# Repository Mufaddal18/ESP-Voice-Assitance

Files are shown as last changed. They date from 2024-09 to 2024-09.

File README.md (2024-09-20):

# ESP-Voice-Assitance

🚀 Excited to share my latest project: a fully integrated PCB for a voice assistant inspired by Avi Patel’s Gemini Voice Assistant!

This innovative design utilizes the Deepgram API for seamless speech-to-text conversion and leverages the Gemini API for intelligent responses, all while harnessing Google Text-to-Speech for natural-sounding replies.

🔑 Key Features:

1. Integrated Components: Powered by the ESP32, featuring a USB to TTL circuit, I2S microphone, and robust amplifier for top-notch performance.

2. Speech-to-Text Conversion: Impressively quick response time with Deepgram API.

3. Smart Audio Switching: Automatically toggles between speaker and earphone output for a personalized listening experience.

4. WAV File Storage: Efficiently processes longer questions by storing them as WAV files on an SD card.

5. Replay Functionality: A dedicated button to replay the last response, enhancing user interaction.

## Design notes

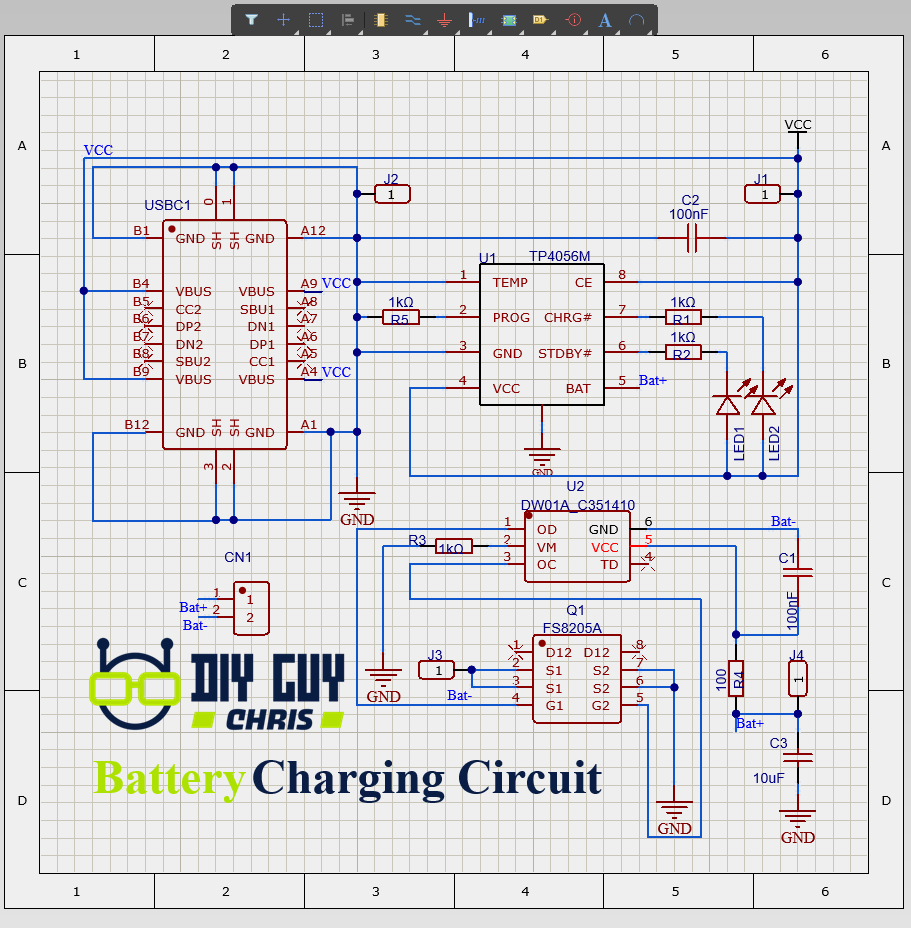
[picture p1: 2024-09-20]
Refrence/FD6H0HMLDD3WI26.webp

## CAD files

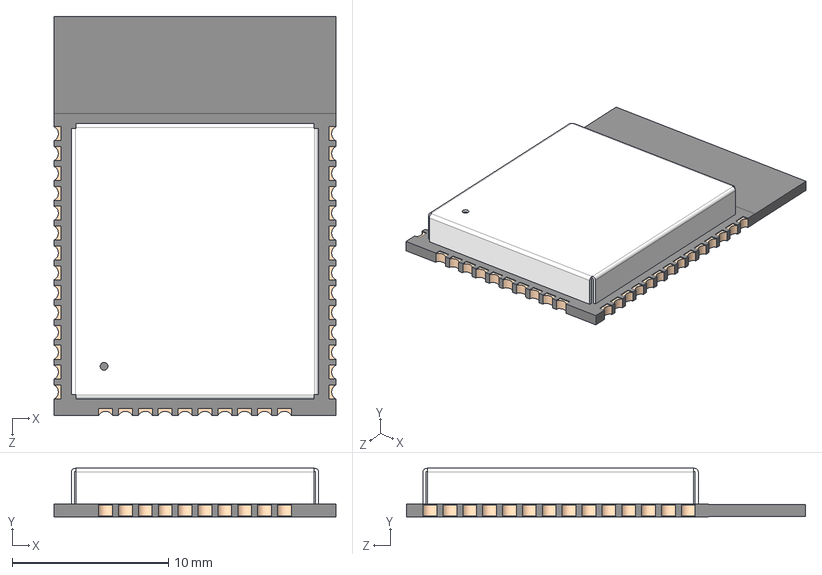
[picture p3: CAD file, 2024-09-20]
3D/ESP32-WROOM-32D/ESP32-WROOM-32D__4MB_PS_.stp
18.0 x 3.10 x 25.5 mm

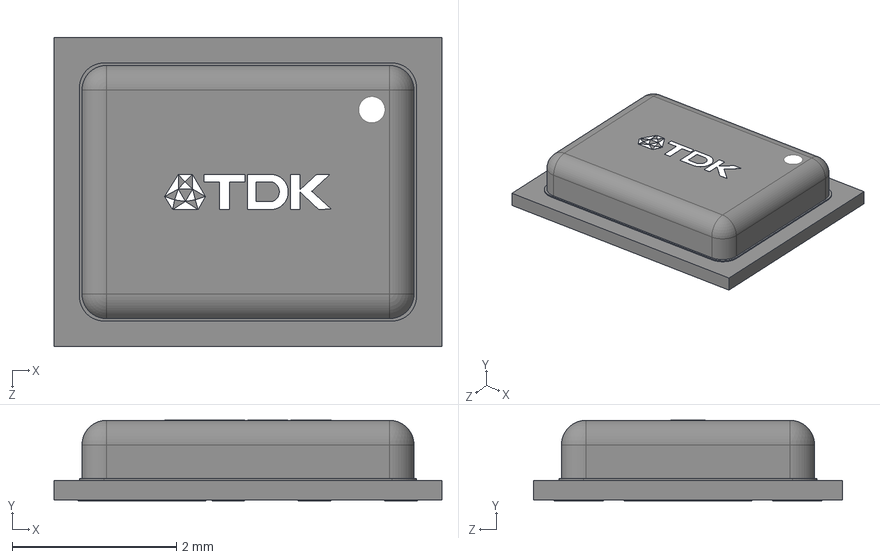
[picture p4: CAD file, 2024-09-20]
3D/INMP441/INMP441.stp
4.72 x 0.981 x 3.76 mm

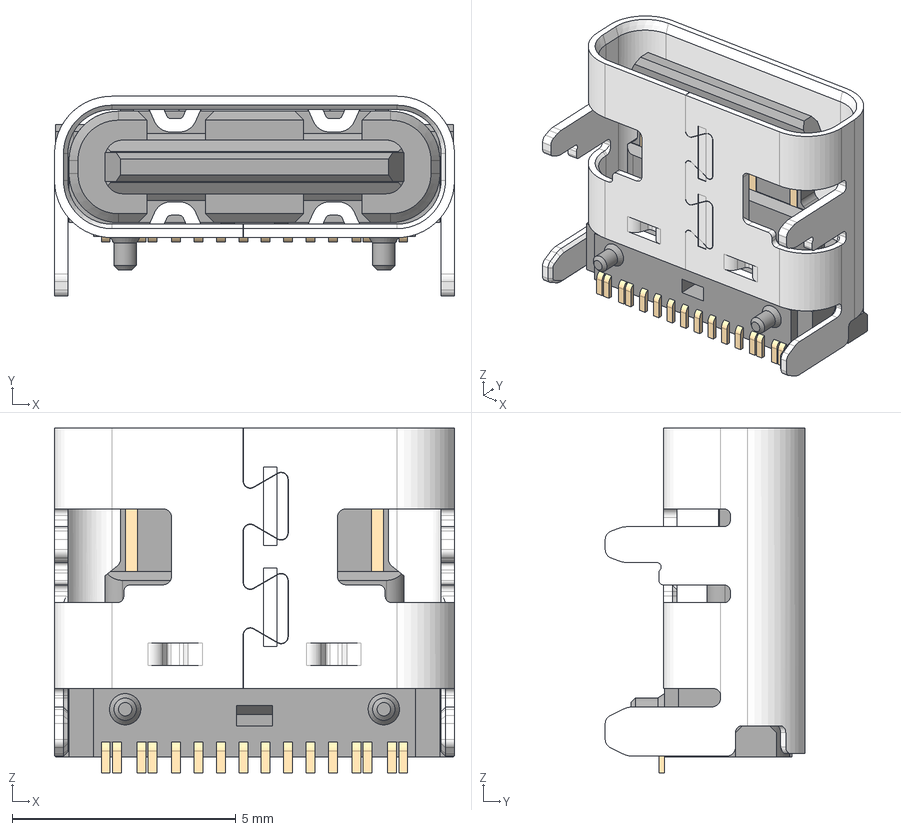
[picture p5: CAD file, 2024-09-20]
3D/KH_Type-C/USB4105-15-A-120.stp
8.94 x 4.46 x 7.70 mm
USB4105-15-A-120_PART2
USB4105-15-A-120_PART1

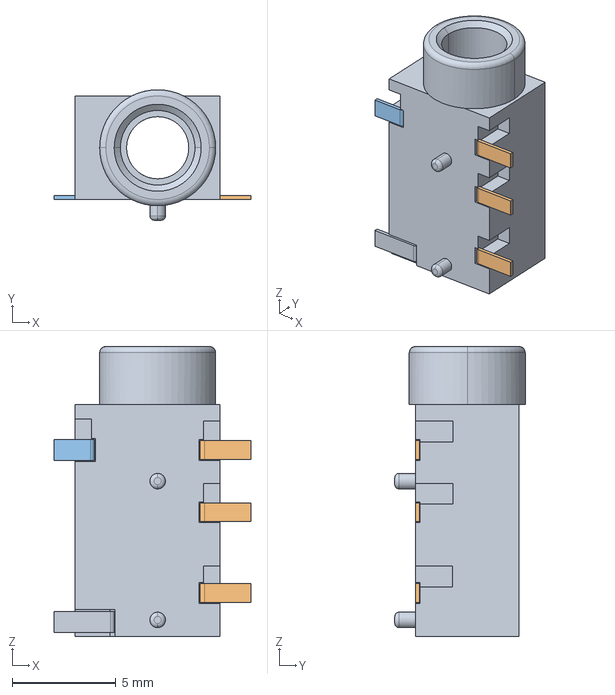
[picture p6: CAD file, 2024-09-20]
3D/PJ-327E-5A/PJ-327E-SMT.stp
9.50 x 6.30 x 14.0 mm

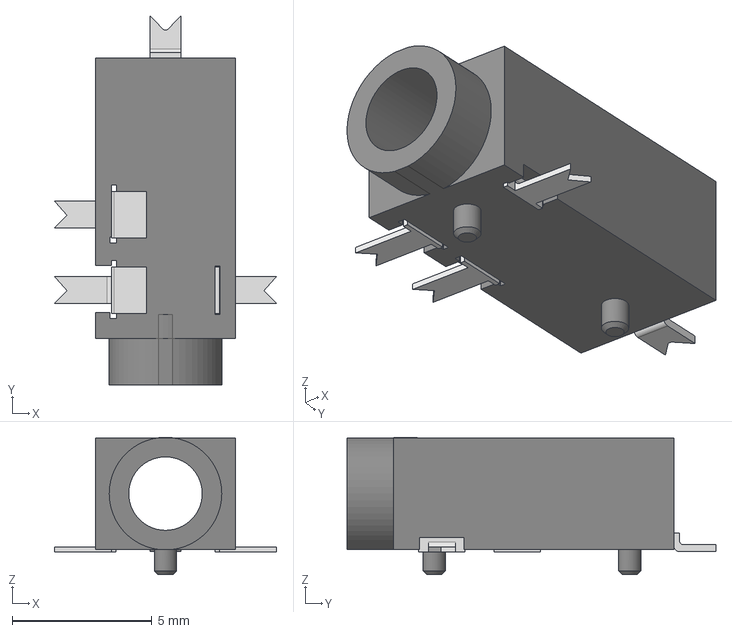
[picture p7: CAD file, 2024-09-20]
3D/SJ-2504A-SMT-TR/SJ-2504A-SMT-TR.stp
7.95 x 13.2 x 4.91 mm

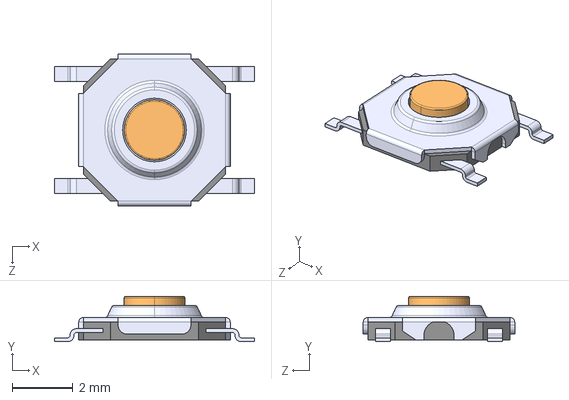
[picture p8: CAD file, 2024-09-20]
3D/Switch/TL3342F160QG_TR.step
6.60 x 1.50 x 5.00 mm

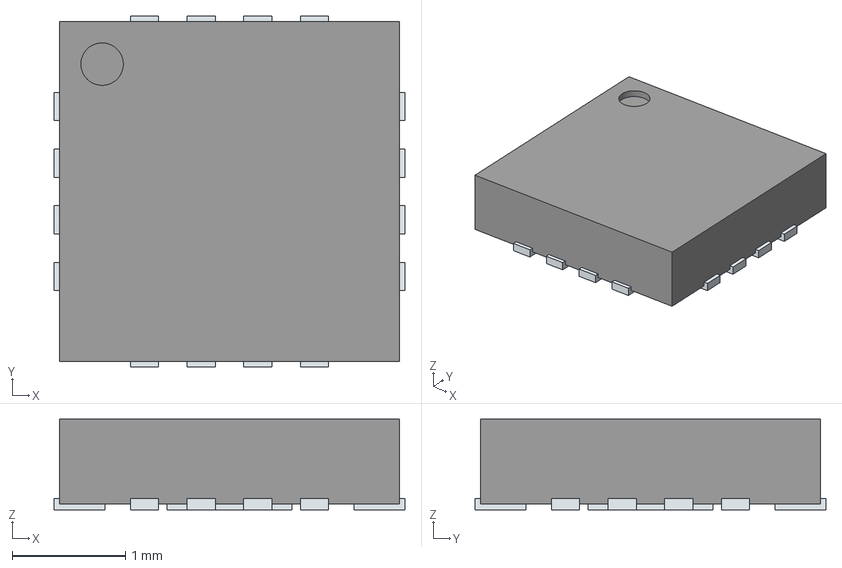
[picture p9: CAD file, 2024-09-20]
3D/MAX98357AGTE_V+T/MAX98357AGTE_V+T.stp
3.10 x 3.10 x 0.8 mm
ThermalPin
PinsArrayLR
PinsArrayTB

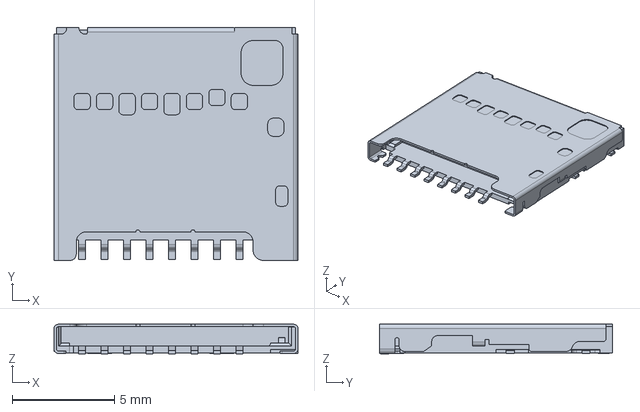
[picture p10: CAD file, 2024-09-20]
3D/SD_card/104031-0811.stp
11.9 x 11.4 x 1.45 mm

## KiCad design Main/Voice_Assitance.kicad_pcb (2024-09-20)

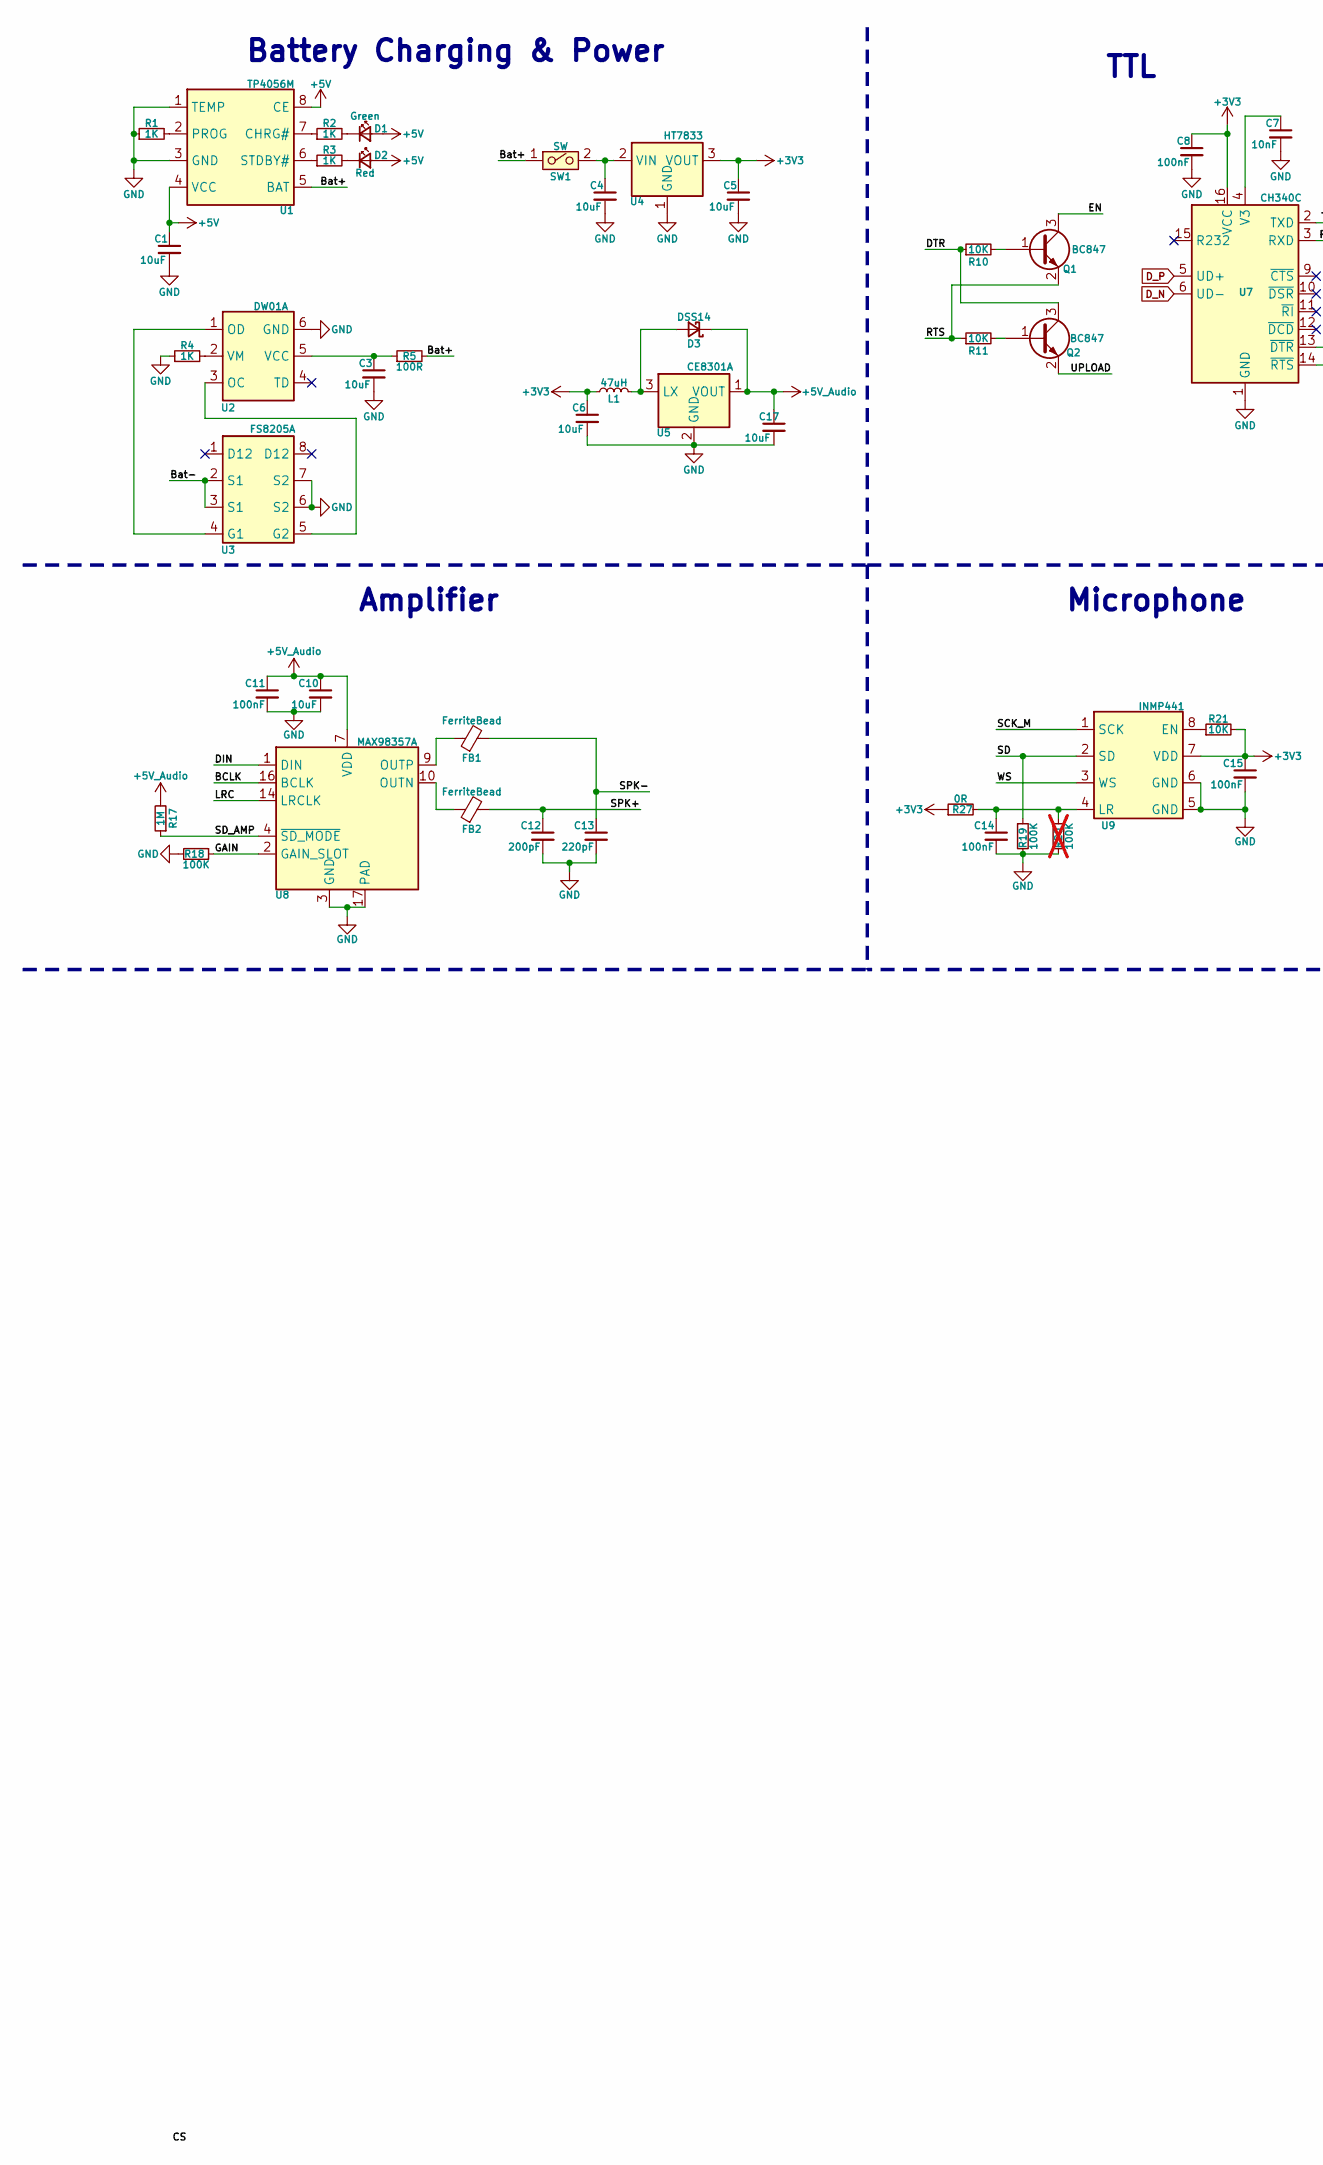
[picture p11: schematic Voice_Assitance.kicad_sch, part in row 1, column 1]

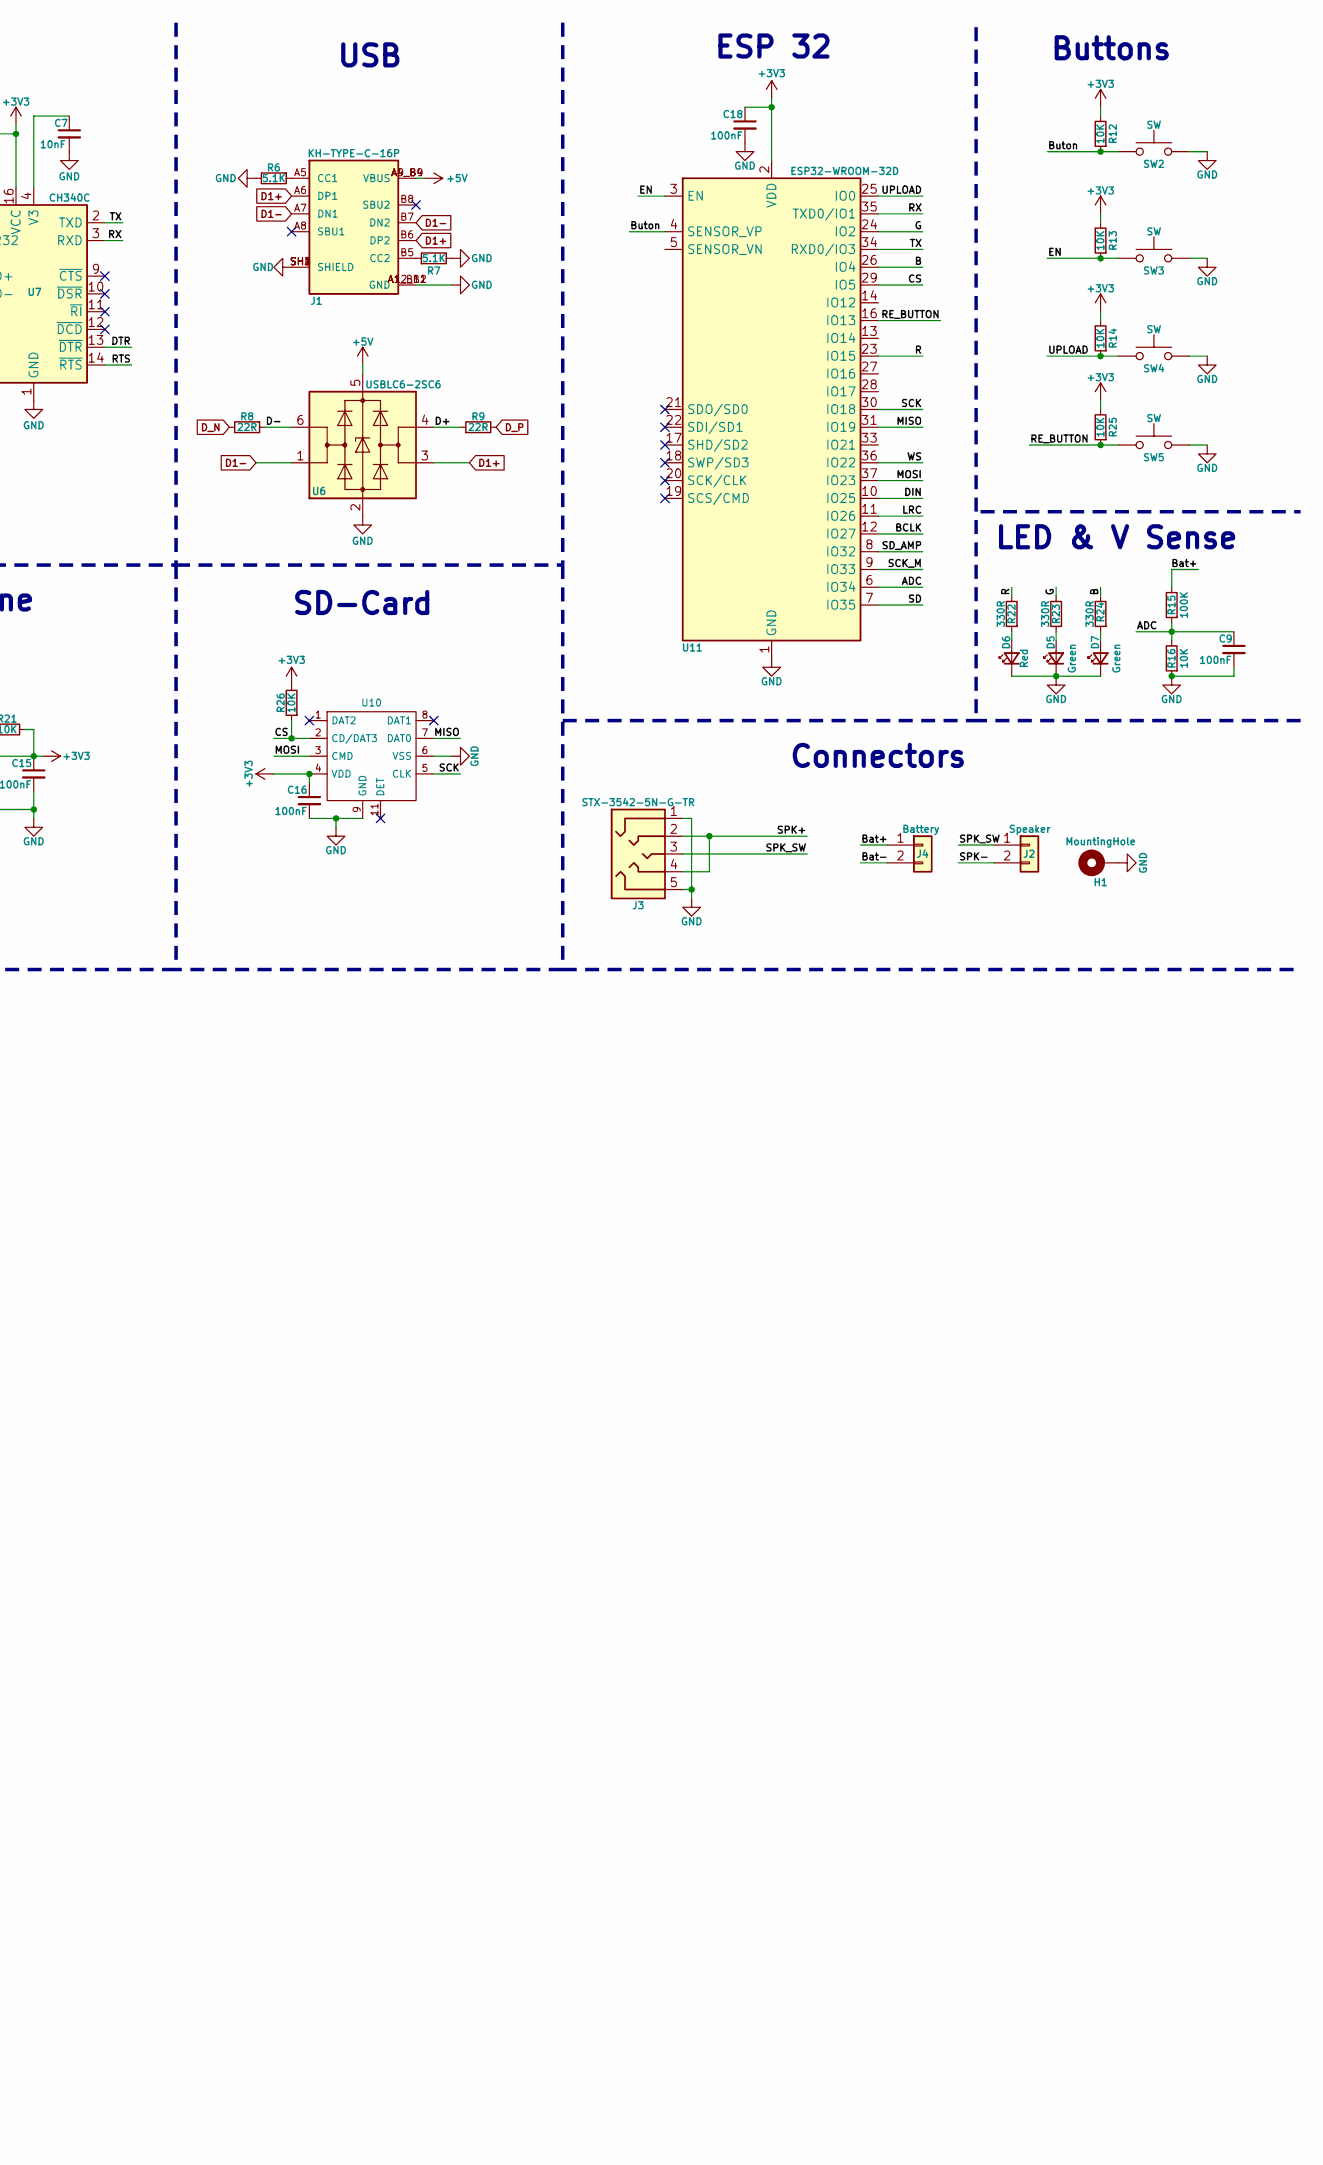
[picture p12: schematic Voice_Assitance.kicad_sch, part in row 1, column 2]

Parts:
C1, C4, C5, C6: 10uF; C_0603_1608Metric_Pad1.08x0.95mm_HandSolder
C3, C10: 10uF; C_0402_1005Metric_Pad0.74x0.62mm_HandSolder
C7: 10nF; C_0402_1005Metric_Pad0.74x0.62mm_HandSolder
C8, C9, C11, C14, C15, C16: 100nF; C_0402_1005Metric_Pad0.74x0.62mm_HandSolder
C12: 200pF; C_0402_1005Metric_Pad0.74x0.62mm_HandSolder
C13: 220pF; C_0402_1005Metric_Pad0.74x0.62mm_HandSolder
C17: 10uF; C_0603_1608Metric
C18: 100nF; C_0603_1608Metric_Pad1.08x0.95mm_HandSolder
D1, D5, D7: Green; LED_0603_1608Metric_Pad1.05x0.95mm_HandSolder
D2, D6: Red; LED_0603_1608Metric_Pad1.05x0.95mm_HandSolder
D3: DSS14; D_SOD-123
FB1, FB2: FerriteBead; L_0402_1005Metric_Pad0.77x0.64mm_HandSolder
H1: MountingHole; MountingHole_4.3mm_M4_Pad
J1: KH-TYPE-C-16P; KINGHELM_KH-TYPE-C-16P
J2: Speaker; PinHeader_1x02_P2.00mm_Vertical
J3: STX-3542-5N-G-TR
J4: Battery; PinHeader_1x02_P2.00mm_Vertical
L1: 47uH; L_0402_1005Metric_Pad0.77x0.64mm_HandSolder
Q1, Q2: BC847; SOT-23
R1, R2, R3, R4: 1K; R_0402_1005Metric_Pad0.72x0.64mm_HandSolder
R5: 100R; R_0402_1005Metric_Pad0.72x0.64mm_HandSolder
R6, R7: 5.1K; R_0402_1005Metric_Pad0.72x0.64mm_HandSolder
R8, R9: 22R; R_0402_1005Metric_Pad0.72x0.64mm_HandSolder
R10, R11, R12, R13, R14, R16, R21, R25, R26: 10K; R_0402_1005Metric_Pad0.72x0.64mm_HandSolder
R15, R18, R19: 100K; R_0402_1005Metric_Pad0.72x0.64mm_HandSolder
R17: 1M; R_0402_1005Metric_Pad0.72x0.64mm_HandSolder
R20: 100K; R_0402_1005Metric_Pad0.72x0.64mm_HandSolder; not fitted
R22, R23, R24: 330R; R_0402_1005Metric_Pad0.72x0.64mm_HandSolder
R27: 0R; R_0402_1005Metric_Pad0.72x0.64mm_HandSolder
SW1: SW; MK-12C03-G015
SW2, SW3, SW4, SW5: SW; SW_TL3342F160QG_TR
U1: TP4056M; MSOP-8-1EP_3x3mm_P0.65mm_EP1.68x1.88mm
U2: DW01A; SOT-23-6
U3: FS8205A; TSSOP-8_4.4x3mm_P0.65mm
U4: HT7833; SOT-89-3
U5: CE8301A; SOT-23-3
U6: USBLC6-2SC6; SOT-23-6
U7: CH340C; SOP-16_3.9x9.9mm_P1.27mm
U8: MAX98357A; MAX98357AGTE_V+T
U9: INMP441
U10: 1040310811
U11: ESP32-WROOM-32D

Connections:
+3V3: C5.1, C6.1, C8.1, C15.1, C16.1, C18.1, L1.1, R12.2, R13.2, R14.2, R21.2, R25.2, R26.2, R27.1, U4.3 (VOUT), U7.16 (VCC), U9.7 (VDD), U10.4 (VDD), U11.2 (VDD)
+5V: C1.1, D1.2 (A), D2.2 (A), J1.A4_B9 (VBUS), J1.A9_B4 (VBUS), U1.4 (VCC), U1.8 (CE), U6.5 (VBUS)
+5V_Audio: C10.1, C11.1, C17.1, D3.1 (K), R17.2, U5.1 (VOUT), U8.7 (VDD), U8.8 (VDD)
/ADC: C9.1, R15.1, R16.2, U11.6 (IO34)
/B: R24.2, U11.26 (IO4)
/BCLK: U8.16 (BCLK), U11.12 (IO27)
/Bat+: J4.1, R5.2, R15.2, SW1.1, U1.5 (BAT)
/Bat-: J4.2, U3.2 (S1), U3.3 (S1)
/Buton: R12.1, SW2.1, U11.4 (SENSOR_VP)
/CS: R26.1, U10.2 (CD/DAT3), U11.29 (IO5)
/D+: R9.1, U6.4 (I/O2)
/D-: R8.1, U6.6 (I/O1)
/DIN: U8.1 (DIN), U11.10 (IO25)
/DTR: Q2.3 (C), R10.1, U7.13 (~DTR)
/EN: Q1.3 (C), R13.1, SW3.1, U11.3 (EN)
/G: R23.2, U11.24 (IO2)
/GAIN: R18.1, U8.2 (GAIN_SLOT)
/LRC: U8.14 (LRCLK), U11.11 (IO26)
/MISO: U10.7 (DAT0), U11.31 (IO19)
/MOSI: U10.3 (CMD), U11.37 (IO23)
/R: R22.2, U11.23 (IO15)
/RE_BUTTON: R25.1, SW5.1, U11.16 (IO13)
/RTS: Q1.2 (E), R11.1, U7.14 (~RTS)
/RX: U7.3 (RXD), U11.35 (TXD0/IO1)
/SCK: U10.5 (CLK), U11.30 (IO18)
/SCK_M: U9.1 (SCK), U11.9 (IO33)
/SD: R19.1, U9.2 (SD), U11.7 (IO35)
/SD_AMP: R17.1, U8.4 (~SD_MODE), U11.8 (IO32)
/SPK+: C12.1, FB2.2, J3.2, J3.4
/SPK-: C13.1, FB1.2, J2.2
/SPK_SW: J2.1, J3.3
/TX: U7.2 (TXD), U11.34 (RXD0/IO3)
/UPLOAD: Q2.2 (E), R14.1, SW4.1, U11.25 (IO0)
/WS: U9.3 (WS), U11.36 (IO22)
D1+: J1.A6 (DP1), J1.B6 (DP2), U6.3 (I/O2)
D1-: J1.A7 (DN1), J1.B7 (DN2), U6.1 (I/O1)
D_N: R8.2, U7.6 (UD-)
D_P: R9.2, U7.5 (UD+)
GND: C1.2, C3.2, C4.2, C5.2, C6.2, C7.2, C8.2, C9.2, C10.2, C11.2, C12.2, C13.2, C14.2, C15.2, C16.2, C17.2, C18.2, D5.1 (K), D6.1 (K), D7.1 (K), H1.1, J1.A1_B12 (GND), J1.A12_B1 (GND), J1.SH1 (SHIELD), J1.SH2 (SHIELD), J1.SH3 (SHIELD), J1.SH4 (SHIELD), J3.1, J3.5, R1.1, R4.1, R6.2, R7.2, R16.1, R18.2, R19.2, R20.2, SW2.2, SW3.2, SW4.2, SW5.2, U1.1 (TEMP), U1.3 (GND), U2.6 (GND), U3.6 (S2), U3.7 (S2), U4.1 (GND), U5.2 (GND), U6.2 (GND), U7.1 (GND), U8.3 (GND), U8.11 (GND), U8.15 (GND), U8.17 (PAD), U9.5 (GND), U9.6 (GND), U9.9 (GND), U10.6 (VSS), U10.9 (GND), U10.10 (GND), U10.12 (GND), U10.13 (GND), U10.14 (GND), U11.1 (GND), U11.15 (GND), U11.38 (GND), U11.39 (GND)
unnamed: D1.1 (K), R2.2
unnamed: D2.1 (K), R3.2
unnamed: D3.2 (A), L1.2, U5.3 (LX)
unnamed: D5.2 (A), R23.1
unnamed: D6.2 (A), R22.1
unnamed: D7.2 (A), R24.1
unnamed: J1.A5 (CC1), R6.1
unnamed: J1.B5 (CC2), R7.1
unnamed: Q1.1 (B), R10.2
unnamed: Q2.1 (B), R11.2
unnamed: R2.1, U1.7 (CHRG#)
unnamed: R1.2, U1.2 (PROG)
unnamed: R3.1, U1.6 (STDBY#)
unnamed: U2.3 (OC), U3.5 (G2)
unnamed: U2.1 (OD), U3.4 (G1)
unnamed: C3.1, R5.1, U2.5 (VCC)
unnamed: R4.2, U2.2 (VM)
unnamed: C4.1, SW1.2, U4.2 (VIN)
unnamed: C7.1, U7.4 (V3)
unnamed: FB2.1, U8.10 (OUTN)
unnamed: FB1.1, U8.9 (OUTP)
unnamed: R21.1, U9.8 (EN)
unnamed: C14.1, R20.1, R27.2, U9.4 (LR)

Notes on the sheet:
TTL
Amplifier
Connectors
SD-Card
Microphone
ESP 32
Battery Charging & Power
Buttons
USB
LED & V Sense

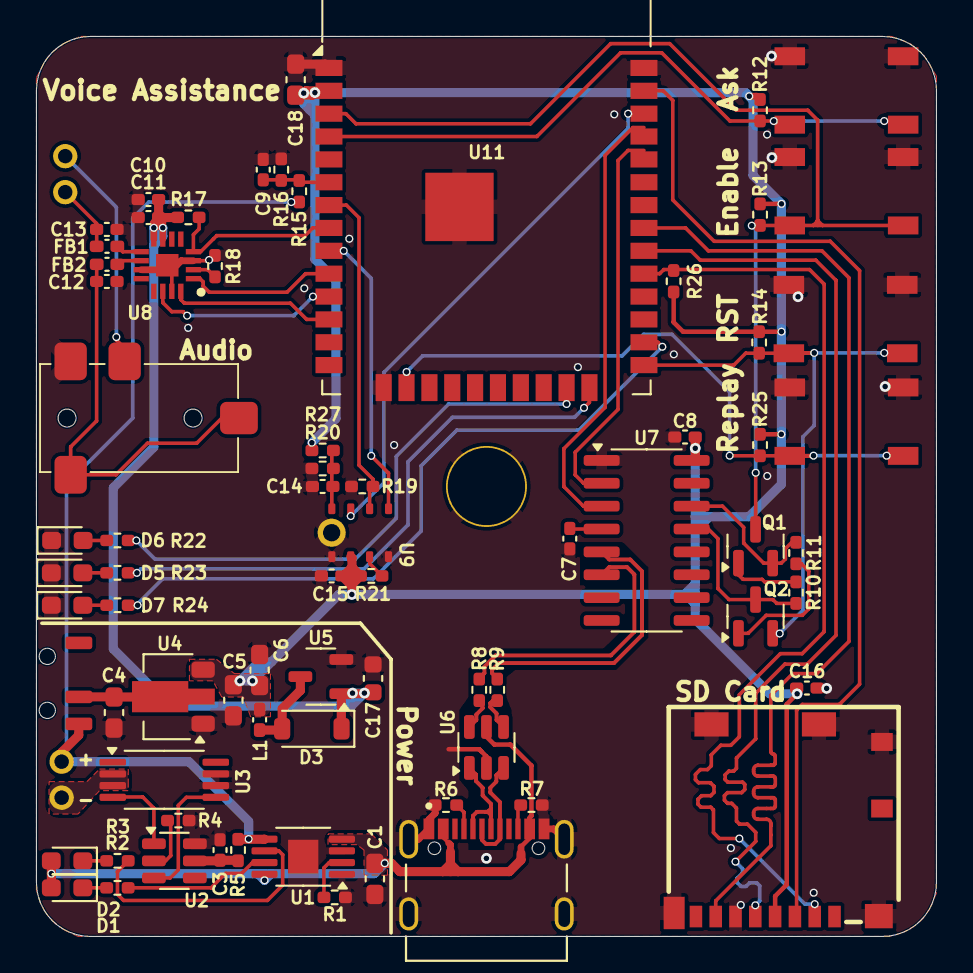
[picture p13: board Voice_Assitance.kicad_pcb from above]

Board: 4 copper layers, 50.0 x 50.0 mm, 76 parts (0 on the bottom side), 62 nets.

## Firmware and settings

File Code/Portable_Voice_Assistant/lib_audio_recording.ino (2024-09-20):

// ------------------------------------------------------------------------------------------------------------------------------
// ----------------  KALO Library - RECORDING audio, storing .wav on SD (variable sample/bit rate, gain booster) ---------------- 
// ----------------                                      July 22, 2024                                           ----------------
// ----------------                                                                                              ---------------- 
// ----------------                Used pins SD Card: VSPI Default pins 5,18,19,23                               ----------------
// ----------------                Used pins I2S Microphone INMP441: WS 22, SCK 33, SD 35                        ----------------
// ----------------                Using latests ESP 3.x library (with I2S_std.h)                                ----------------
// ----------------                                                                                              ----------------
// ----------------   bool I2S_Record_Init();                // Initialization (once)                            ----------------
// ----------------   bool Record_Start(file);               // appending I2S buffer to file (in loop, ongoing)  ----------------
// ----------------   bool Record_Available(file, &duration) // stop recording (once)                            ----------------
// ------------------------------------------------------------------------------------------------------------------------------


// *** HINT: in case of an 'Sketch too Large' Compiler Warning/ERROR in Arduino IDE (ESP32 Dev Module:
// -> select a larger 'Partition Scheme' via menu > tools: e.g. using 'No OTA (2MB APP / 2MB SPIFFS) ***


#include "driver/i2s_std.h"     // instead of older legacy #include <driver/i2s.h>  
/* #include <SD.h>              // also needed, but already included in Main.ino */


// --- defines & macros --------

#ifndef DEBUG                   // user can define favorite behaviour ('true' displays addition info)
#  define DEBUG true            // <- define your preference here  
#  define DebugPrint(x);        if(DEBUG){Serial.print(x);}   /* do not touch */
#  define DebugPrintln(x);      if(DEBUG){Serial.println(x);} /* do not touch */ 
#endif


// --- PIN assignments ---------

#define I2S_WS      22          // add-on: L/R pin INMP441 on Vcc is RIGHT channel, connected to GND is LEFT channel
#define I2S_SD      35          
#define I2S_SCK     33     


// --- define your settings ----

#define SAMPLE_RATE             16000  // typical values: 8000 .. 44100, use e.g 8K (and 8 bit mono) for smallest .wav files  
                                       // hint: best quality with 16000 or 24000 (above 24000: random dropouts and distortions)
                                       // recommendation in case the STT service produces lot of wrong words: try 16000 

#define BITS_PER_SAMPLE         8      // 16 bit and 8bit supported (24 or 32 bits not supported)
                                       // hint: 8bit is less critical for STT services than a low 8kHz sample rate
                                       // for fastest STT: combine 8kHz and 8 bit. 

#define GAIN_BOOSTER_I2S        45     // original I2S streams is VERY silent, so we added an optional GAIN booster for INMP441
                                       // multiplier, values: 1-64 (32 seems best value for INMP441)
                                       // 64: high background noise but working well for STT on quiet human conversations


/*// Links of interest:
// SD Card Arduino library info: https://www.arduino.cc/reference/en/libraries/sd/
// SD Card ESP details: https://randomnerdtutorials.com/esp32-microsd-card-arduino/
// Dronebot I2S workshop: https://dronebotworkshop.com/esp32-i2s/ (using old I2S.h)
// Link WAV header: http://soundfile.sapp.org/doc/WaveFormat/
// Using tabs to organize code with the Arduino IDE: https://www.youtube.com/watch?v=HtYlQXt14zU */

// Code below is mainly based on Espressif API I2S Reference Doc (Latest Master, 3.0.1, June 2024)
// link: https://docs.espressif.com/projects/esp-idf/en/latest/esp32/api-reference/peripherals/i2s.html#introduction
// snippets here: https://github.com/espressif/esp-adf/issues/1047 


// --- global vars -------------

// [std_cfg]: KALO I2S_std configuration for I2S Input device (Microphone INMP441), detailed definitions (without macros)
// Details see: 'i2s_std.h' 

i2s_std_config_t  std_cfg = 
{ .clk_cfg  =   // instead of macro 'I2S_STD_CLK_DEFAULT_CONFIG(SAMPLE_RATE),'
  { .sample_rate_hz = SAMPLE_RATE,
    .clk_src = I2S_CLK_SRC_DEFAULT,
    .mclk_multiple = I2S_MCLK_MULTIPLE_256,
  },
  .slot_cfg =   // instead of macro I2S_STD_MSB_SLOT_DEFAULT_CONFIG(I2S_DATA_BIT_WIDTH_16BIT, I2S_SLOT_MODE_STEREO),
  { // hint: always using _16BIT because I2S uses 16 bit slots anyhow (even in case I2S_DATA_BIT_WIDTH_8BIT used !)
    .data_bit_width = I2S_DATA_BIT_WIDTH_16BIT,   // not I2S_DATA_BIT_WIDTH_8BIT or (i2s_data_bit_width_t) BITS_PER_SAMPLE  
    .slot_bit_width = I2S_SLOT_BIT_WIDTH_AUTO, 
    .slot_mode = I2S_SLOT_MODE_MONO,              // or I2S_SLOT_MODE_STEREO
    .slot_mask = I2S_STD_SLOT_RIGHT,              // use 'I2S_STD_SLOT_LEFT' in case L/R pin is connected to GND !
    .ws_width =  I2S_DATA_BIT_WIDTH_16BIT,           
    .ws_pol = false, 
    .bit_shift = true,   // using [.bit_shift = true] similar PHILIPS or PCM format (NOT 'false' as in MSB macro) ! ..
    .msb_right = false,  // .. or [.msb_right = true] to avoid overdriven and distorted signals on I2S microphones
  },
  .gpio_cfg =   
  { .mclk = I2S_GPIO_UNUSED,
    .bclk = (gpio_num_t) I2S_SCK,
    .ws   = (gpio_num_t) I2S_WS,
    .dout = I2S_GPIO_UNUSED,
    .din  = (gpio_num_t) I2S_SD,
    .invert_flags = 
    { .mclk_inv = false,
      .bclk_inv = false,
      .ws_inv = false,
    },
  },
};

// [re_handle]: global handle to the RX channel with channel configuration [std_cfg]
i2s_chan_handle_t  rx_handle;
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

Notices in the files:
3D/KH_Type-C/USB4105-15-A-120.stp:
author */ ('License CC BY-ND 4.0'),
